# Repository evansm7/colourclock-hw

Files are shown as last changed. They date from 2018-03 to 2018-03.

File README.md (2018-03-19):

RGB Colourclock hardware design
===============================

19th March 2018

My Colourclock is a circular wall clock with 60 RGB LEDs.  See <http://www.axio.ms/projects/2018/03/19/Colourclock.html> for information/pictures, and <http://github.com/evansm7/colourclock-fw> for firmware.

This repository contains:

*    Eagle schematic and board files
*    A simple BOM
*    Assembly jig diagram
*    Perl script to automatically create the outline of a single PCB, which is one quarter of a ring of PCBs.  The script also places the 15 RGB LED footprints at the correct locations.

This will hopefully serve as an example for similar designs, and show you how to automate PCB creation using Eagle .brd files (>= version 6).  The workflow was roughly as follows:

*    Create the schematic
*    Create a basic .brd file with instances of LEDs D1 to D15
*    Run this .brd file through the ```mkboard.pl ``` script
*    Tweak the parameters until the size/placement/spacing looks good.

It's possible to change the board outline even after you've routed most of it (and have run out of space...).

* * *

These files are copyright (c) 2014 Matt Evans.  You are permitted to make use of these designs for non-commercial or educational purposes.

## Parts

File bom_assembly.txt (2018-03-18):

Fit on all boards in ring:

Q1,Q2,Q3	DMG2305UX-13	P-Ch FET
Q4,Q5,Q6	KSC2715YMTF_Q	NPN BJT

U2	STP16CPC26XTR

C1	4.7uF
C3	10nF
C5	0.1uF
C6	0.1uF
C10	2.2uF
C4	1uF
C13	1uF

R2	680
R3	4k7
R5	4k7
R7	4k7
R1	10k
R4	10k
R6	10k

SJ2	Close jumper on boards #2,3,4 but not board #1

Fit on board #1 only:

U1	STM32F051C6T6		Cortex-M0
U3	AP2204K-3.3TRG1		150mA CMOS LDO 
D16	CDSUR101A		Small switching diode
C2	220uF
C7	12.5pF
C8	470pF
C9	1uF
C11	12.5pF
C12	0.1uF
X2	CFS206-32.768KDZF-UB	32KHz crystal	
R13	50k
LDR

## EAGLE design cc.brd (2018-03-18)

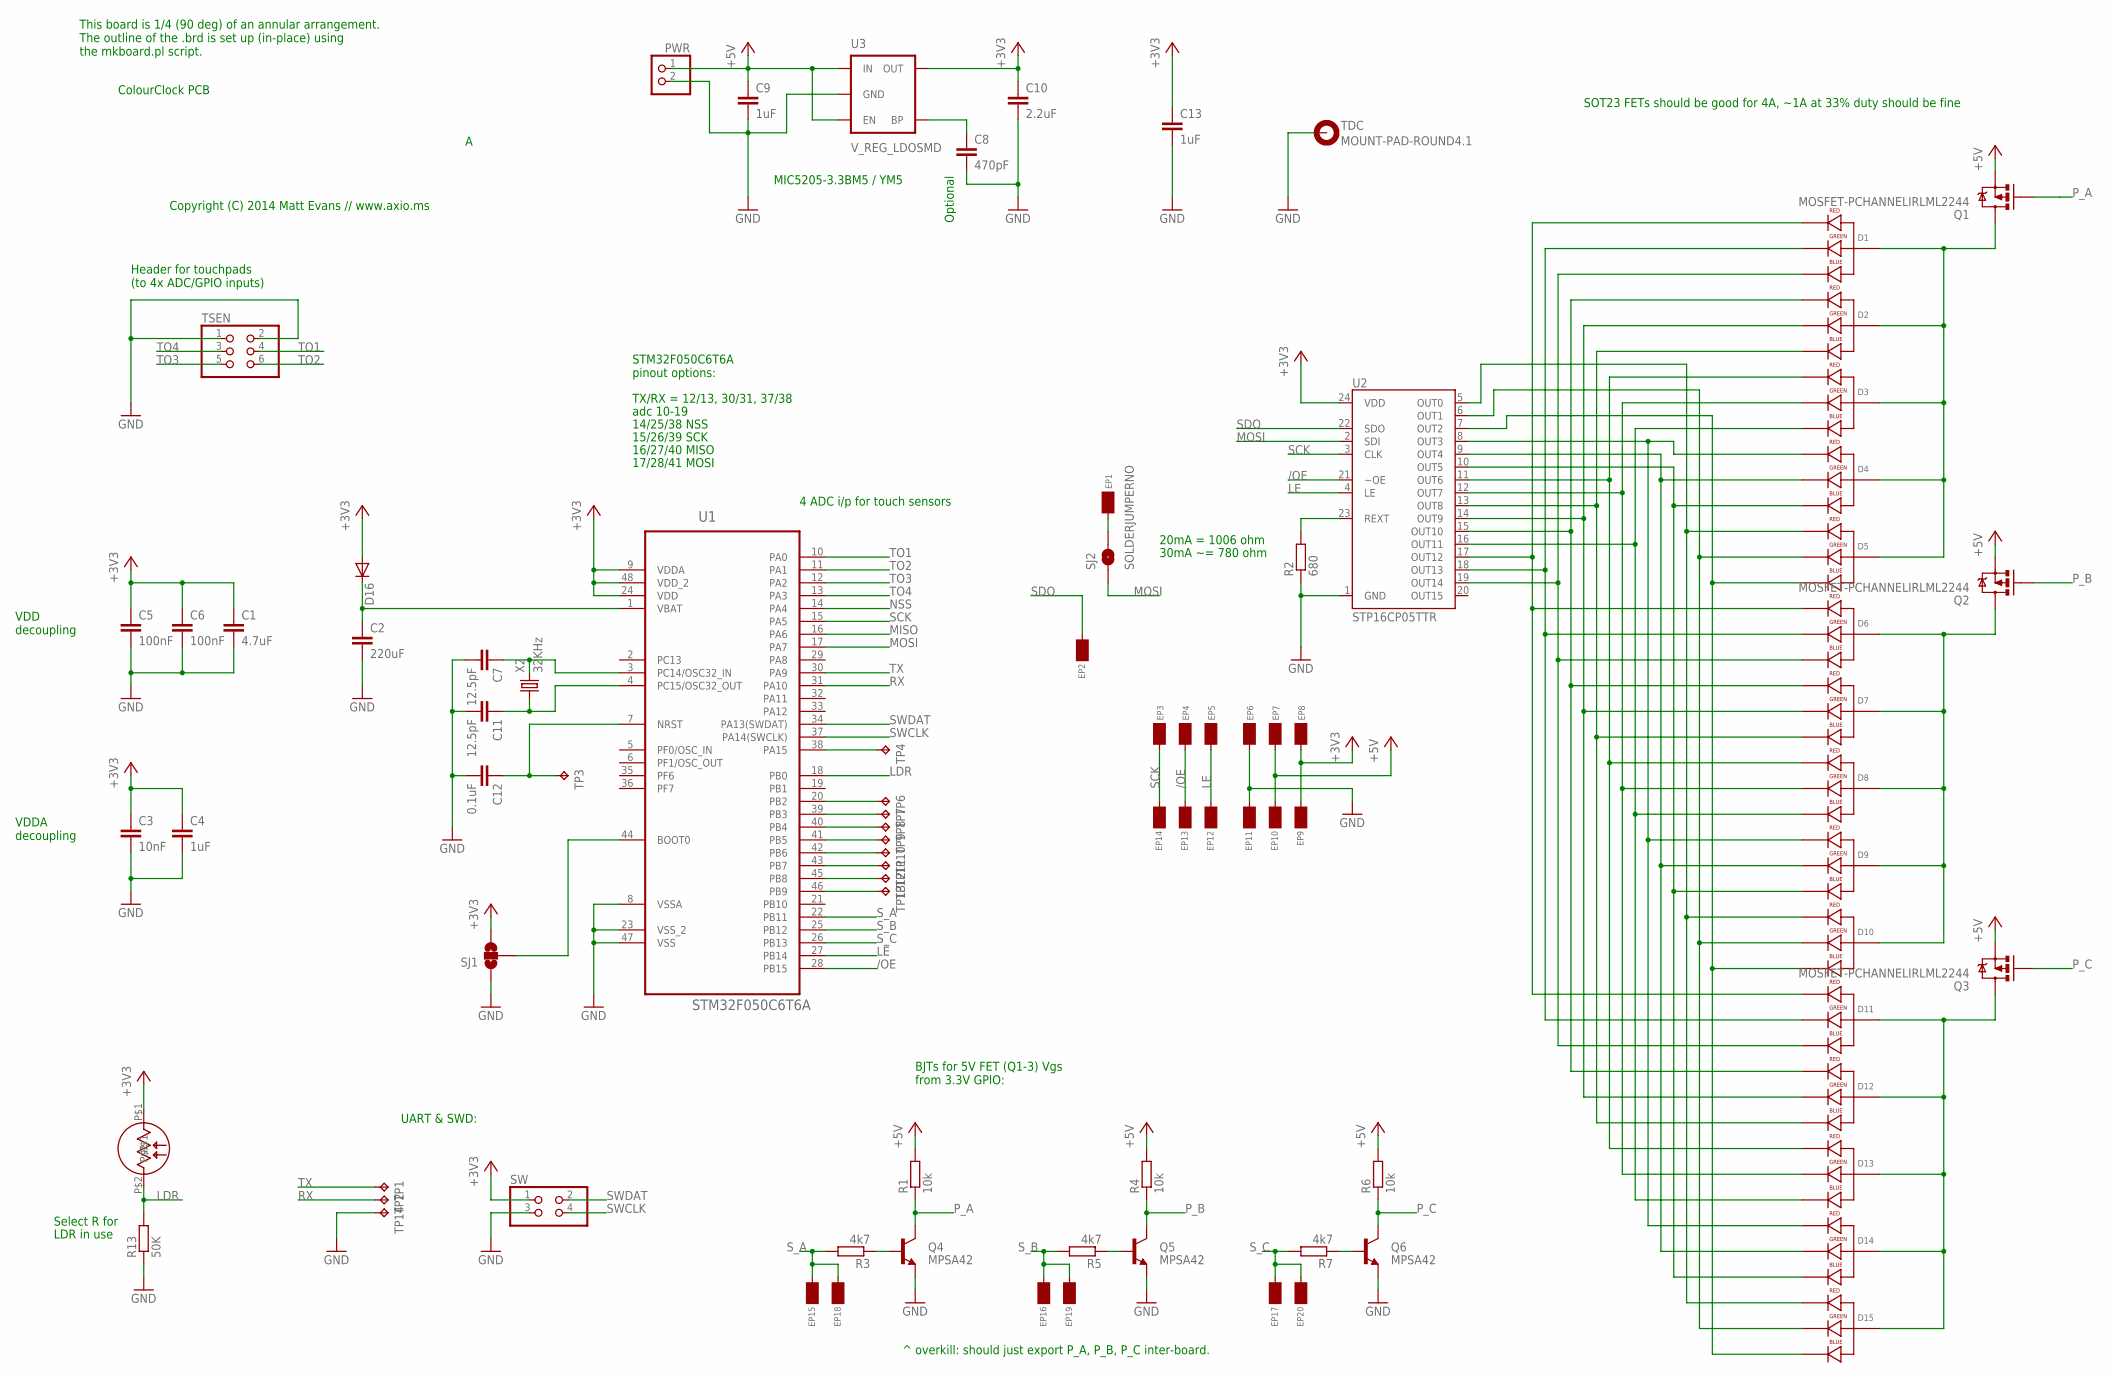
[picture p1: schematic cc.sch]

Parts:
C1: 4.7uF; C0603
C2: 220uF; C1210K
C3: 10nF; C0603
C4, C9, C13: 1uF; C0603
C5, C6: 100nF; C0603
C7, C11: 12.5pF; C1005
C8: 470pF; C0603
C10: 2.2uF; C0603
C12: 0.1uF; C1005
D1, D2, D3, D4, D5, D6, D7, D8, D9, D10, D11, D12, D13, D14, D15: LED-RGB-CA-THRUDIFFUSE; LED-RGB-THRU
D16: DIODESOD; SOD-323
EP1, EP2, EP3, EP4, EP5, EP6, EP7, EP8, EP9, EP10, EP11, EP12, EP13, EP14, EP15, EP16, EP17, EP18, EP19, EP20: EDGEPAD
LDR: VT935G
PWR: PINHD-1X22MM; 1X02-2MM
Q1, Q2, Q3: MOSFET-PCHANNELIRLML2244; SOT23-3
Q4, Q5, Q6: MPSA42; SOT23-3
R1, R4, R6: 10k; R0603
R2: 680; R0603
R3, R5, R7: 4k7; R0603
R13: 50K; R0603
SJ1: SOLDERJUMPER_2WAYS; SJ_3
SJ2: SOLDERJUMPERNO; SJ_2S-NO
SW: PINHD-2X22MM; 2X02-2MM
TDC: MOUNT-PAD-ROUND4.1; 4,1-PAD
TP1, TP2, TP3, TP4, TP6, TP7, TP8, TP9, TP10, TP11, TP12, TP13, TP14: TPTP06R; TP06R
TSEN: PINHD-2X32MM; 2X03-2MM
U1: STM32F050C6T6A; QFP50P900X900X160-48N
U2: STP16CP05TTR; TSSOP24
U3: V_REG_LDOSMD; SOT23-5
X2: 32KHz; TC26V

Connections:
+3V3: C1.1, C3.1, C4.1, C5.1, C6.1, C10.1, C13.1, D16.2 (A), EP8.1, EP9.1, LDR.P$1, SJ1.3, SW.1, U1.9 (VDDA), U1.24 (VDD), U1.48 (VDD_2), U2.24 (VDD), U3.5 (OUT)
+5V: C9.1, EP7.1, EP10.1, PWR.1, Q1.2 (S), Q2.2 (S), Q3.2 (S), R1.2, R4.2, R6.2, U3.1 (IN), U3.3 (EN)
/OE: EP4.1, EP13.1, U1.28 (PB15), U2.21 (~OE)
GND: C1.2, C2.2, C3.2, C4.2, C5.2, C6.2, C7.2, C8.2, C9.2, C10.2, C11.2, C12.2, C13.2, EP6.1, EP11.1, PWR.2, Q4.2 (E), Q5.2 (E), Q6.2 (E), R2.1, R13.1, SJ1.1, SW.3, TDC.B4,1, TP14.TP, TSEN.1, TSEN.2, U1.8 (VSSA), U1.23 (VSS_2), U1.47 (VSS), U2.1 (GND), U3.2 (GND)
LDR: LDR.P$2, R13.2, U1.18 (PB0)
LE: EP5.1, EP12.1, U1.27 (PB14), U2.4 (LE)
MISO: U1.16 (PA6)
MOSI: SJ2.1, U1.17 (PA7), U2.2 (SDI)
unnamed: D1.1 (RED_CATHODE), D6.1 (RED_CATHODE), D11.1 (RED_CATHODE), U2.17 (OUT12)
unnamed: D1.3 (GREEN_CATHODE), D6.3 (GREEN_CATHODE), D11.3 (GREEN_CATHODE), U2.18 (OUT13)
unnamed: D1.4 (BLUE_CATHODE), D6.4 (BLUE_CATHODE), D11.4 (BLUE_CATHODE), U2.19 (OUT14)
unnamed: D2.1 (RED_CATHODE), D7.1 (RED_CATHODE), D12.1 (RED_CATHODE), U2.15 (OUT10)
unnamed: D2.3 (GREEN_CATHODE), D7.3 (GREEN_CATHODE), D12.3 (GREEN_CATHODE), U2.14 (OUT9)
unnamed: D2.4 (BLUE_CATHODE), D7.4 (BLUE_CATHODE), D12.4 (BLUE_CATHODE), U2.13 (OUT8)
unnamed: D3.1 (RED_CATHODE), D8.1 (RED_CATHODE), D13.1 (RED_CATHODE), U2.11 (OUT6)
unnamed: D3.3 (GREEN_CATHODE), D8.3 (GREEN_CATHODE), D13.3 (GREEN_CATHODE), U2.12 (OUT7)
unnamed: D3.4 (BLUE_CATHODE), D8.4 (BLUE_CATHODE), D13.4 (BLUE_CATHODE), U2.16 (OUT11)
unnamed: D4.1 (RED_CATHODE), D9.1 (RED_CATHODE), D14.1 (RED_CATHODE), U2.8 (OUT3)
unnamed: D4.3 (GREEN_CATHODE), D9.3 (GREEN_CATHODE), D14.3 (GREEN_CATHODE), U2.9 (OUT4)
unnamed: D4.4 (BLUE_CATHODE), D9.4 (BLUE_CATHODE), D14.4 (BLUE_CATHODE), U2.10 (OUT5)
unnamed: D5.1 (RED_CATHODE), D10.1 (RED_CATHODE), D15.1 (RED_CATHODE), U2.5 (OUT0)
unnamed: D5.3 (GREEN_CATHODE), D10.3 (GREEN_CATHODE), D15.3 (GREEN_CATHODE), U2.6 (OUT1)
unnamed: D5.4 (BLUE_CATHODE), D10.4 (BLUE_CATHODE), D15.4 (BLUE_CATHODE), U2.7 (OUT2)
unnamed: C7.1, U1.3 (PC14/OSC32_IN), X2.2
unnamed: C11.1, U1.4 (PC15/OSC32_OUT), X2.1
unnamed: R2.2, U2.23 (REXT)
unnamed: C2.1, D16.1 (C), U1.1 (VBAT)
unnamed: TP8.TP, U1.40 (PB4)
unnamed: TP7.TP, U1.39 (PB3)
unnamed: EP1.1, SJ2.2
unnamed: TP6.TP, U1.20 (PB2)
unnamed: Q5.1 (B), R5.1
unnamed: C12.1, TP3.TP, U1.7 (NRST)
unnamed: Q4.1 (B), R3.1
unnamed: D11.2 (ANODE), D12.2 (ANODE), D13.2 (ANODE), D14.2 (ANODE), D15.2 (ANODE), Q3.3 (D)
unnamed: D6.2 (ANODE), D7.2 (ANODE), D8.2 (ANODE), D9.2 (ANODE), D10.2 (ANODE), Q2.3 (D)
unnamed: D1.2 (ANODE), D2.2 (ANODE), D3.2 (ANODE), D4.2 (ANODE), D5.2 (ANODE), Q1.3 (D)
unnamed: C8.1, U3.4 (BP)
unnamed: TP4.TP, U1.38 (PA15)
unnamed: SJ1.2, U1.44 (BOOT0)
unnamed: Q6.1 (B), R7.1
unnamed: TP9.TP, U1.41 (PB5)
unnamed: TP10.TP, U1.42 (PB6)
unnamed: TP11.TP, U1.43 (PB7)
unnamed: TP12.TP, U1.45 (PB8)
unnamed: TP13.TP, U1.46 (PB9)
NSS: U1.14 (PA4)
P_A: Q1.1 (G), Q4.3 (C), R1.1
P_B: Q2.1 (G), Q5.3 (C), R4.1
P_C: Q3.1 (G), Q6.3 (C), R6.1
RX: TP2.TP, U1.31 (PA10)
SCK: EP3.1, EP14.1, U1.15 (PA5), U2.3 (CLK)
SDO: EP2.1, U2.22 (SDO)
SWCLK: SW.4, U1.37 (PA14(SWCLK))
SWDAT: SW.2, U1.34 (PA13(SWDAT))
S_A: EP15.1, EP18.1, R3.2, U1.22 (PB11)
S_B: EP16.1, EP19.1, R5.2, U1.25 (PB12)
S_C: EP17.1, EP20.1, R7.2, U1.26 (PB13)
TO1: TSEN.4, U1.10 (PA0)
TO2: TSEN.6, U1.11 (PA1)
TO3: TSEN.5, U1.12 (PA2)
TO4: TSEN.3, U1.13 (PA3)
TX: TP1.TP, U1.30 (PA9)

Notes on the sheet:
Select R for
LDR in use
20mA = 1006 ohm
30mA ~= 780 ohm
Optional
VDDA decoupling
VDD decoupling
17/28/41 MOSI
16/27/40 MISO
15/26/39 SCK
14/25/38 NSS
adc 10-19
TX/RX = 12/13, 30/31, 37/38
SOT23 FETs should be good for 4A, ~1A at 33% duty should be fine
4 ADC i/p for touch sensors
Header for touchpads (to 4x ADC/GPIO inputs)
STM32F050C6T6A pinout options:
UART & SWD:
BJTs for 5V FET (Q1-3) Vgs from 3.3V GPIO:
ColourClock PCB
This board is 1/4 (90 deg) of an annular arrangement. The outline of the .brd is set up (in-place) using the mkboard.pl script.
MIC5205-3.3BM5 / YM5
^ overkill: should just export P_A, P_B, P_C inter-board.
Copyright (C) 2014 Matt Evans // www.axio.ms

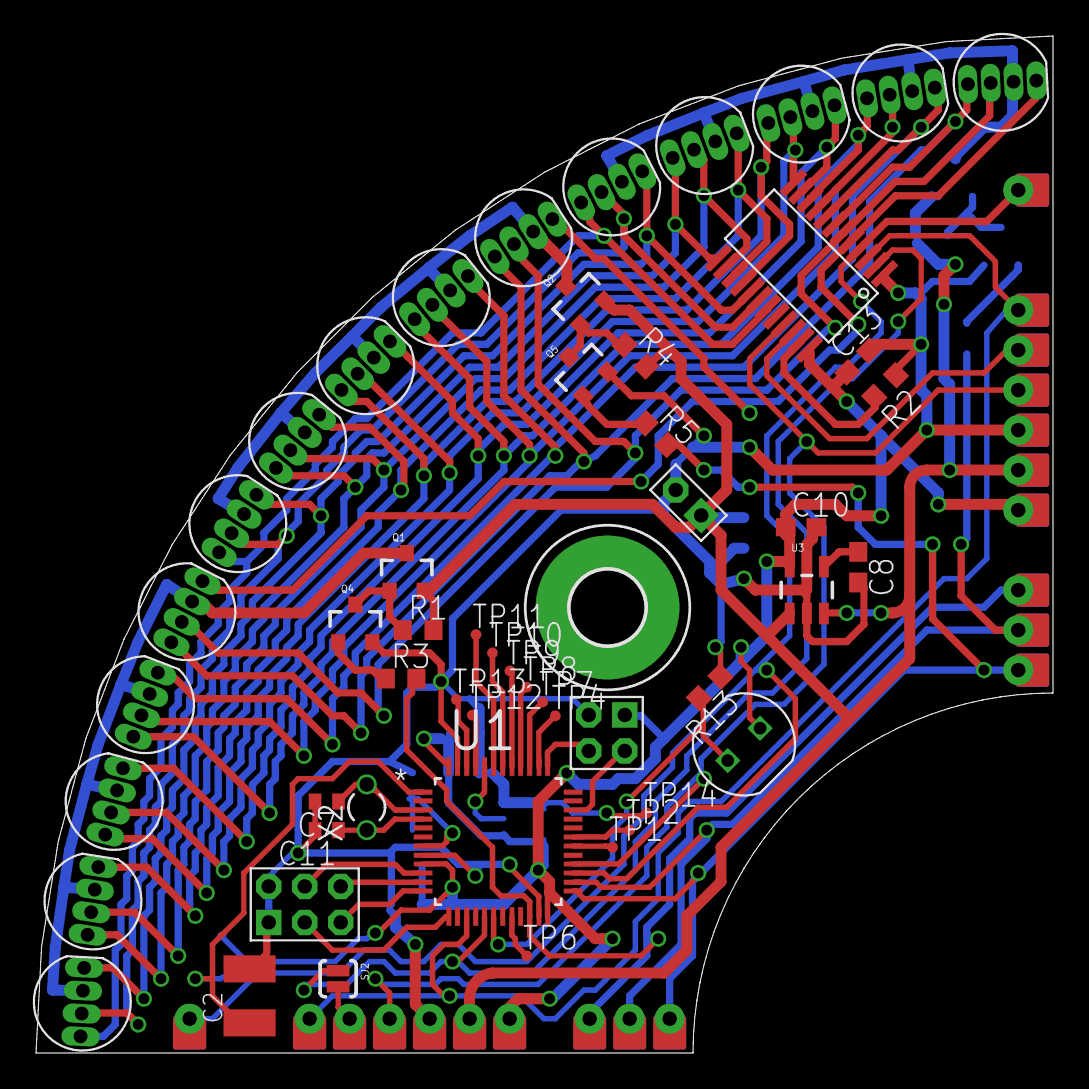
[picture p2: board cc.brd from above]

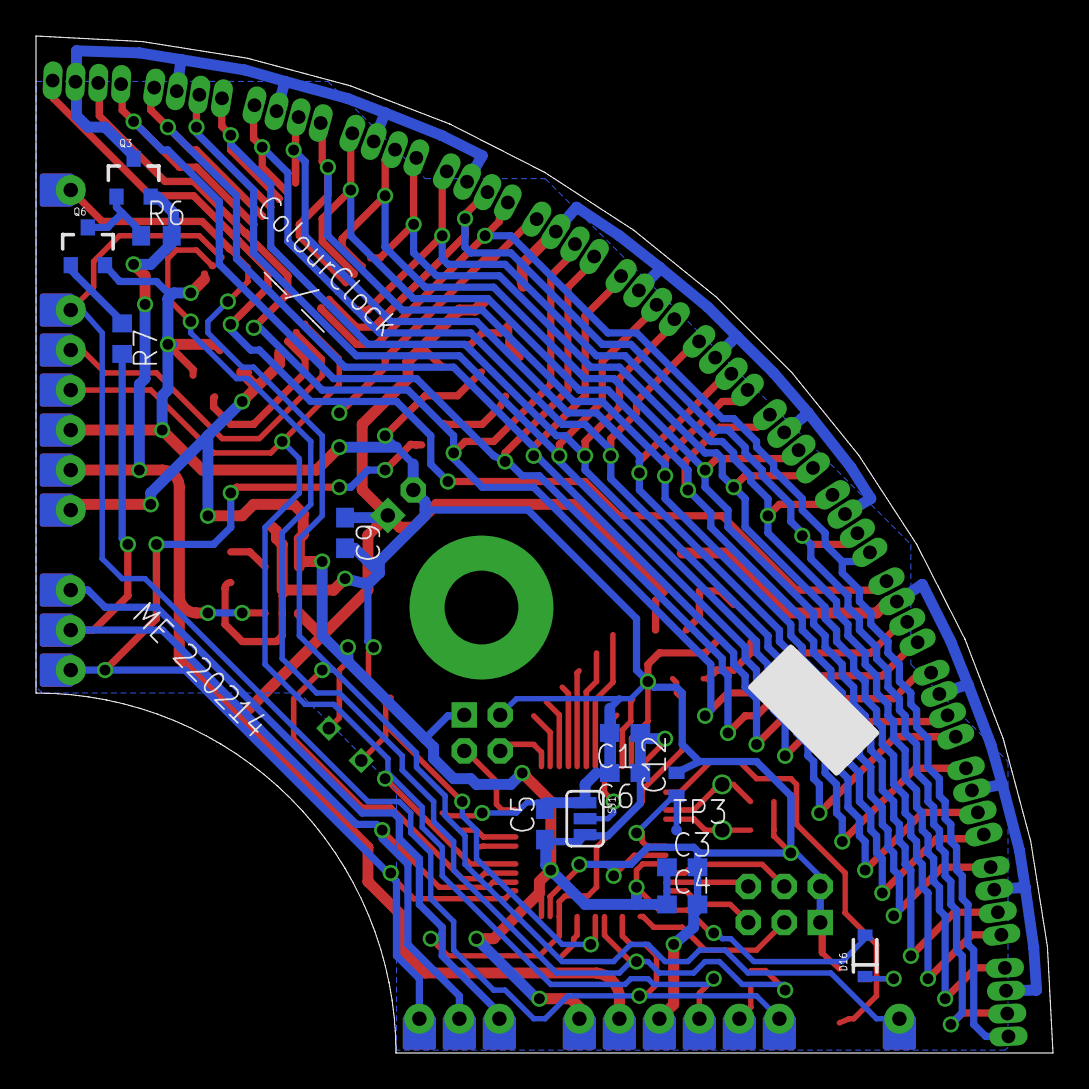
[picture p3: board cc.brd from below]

Board: 4 copper layers, 56.5 x 56.5 mm, 87 parts (14 on the bottom side), 61 nets.

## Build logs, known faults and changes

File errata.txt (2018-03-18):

Revision A errata:

1:	Footprint for D16 too small (or D16 too big)

2:	Pin 1 of 4-pin jumper 'SW' is 3.3V; it would be more useful to have routed nRST to this pin (as reset is useful to have alongside SWD).

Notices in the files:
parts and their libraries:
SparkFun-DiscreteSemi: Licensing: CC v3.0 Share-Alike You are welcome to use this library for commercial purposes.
